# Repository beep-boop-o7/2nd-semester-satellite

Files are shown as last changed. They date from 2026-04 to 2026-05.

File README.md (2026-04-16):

# 2nd-semester-satellite

## Includes
Put your nonstandard library includes here (the ones you had to install separately)
available in the arduino ide unless otherwise noted

## How to use git (and github)
make sure git is installed.

### Setup

initilize a git instance in the directory(folder) that you want the project stored in
```
git init
```

clone the repo(repository) (copy it to your computer)
```
git clone https://github.com/beep-boop-o7/2nd-semester-satellite.git
```

set repo as origin
```
git remote add origin https://github.com/beep-boop-o7/2nd-semester-satellite.git
```

### Using

make a new branch for the feature you are working on (only do this for new features)
```
git checkout -b subsystem/feature_name
```

add changes to local branch (add all untracked)
```
git add -i
```

commit the changes you have made to the local branch (with a brief description)
```
git commit -m "This is a brief description"
```

push your local branch upstream (to github)
```
git push -u origin subsystem/feature_name
```
after that you go into github to make a merge request to merge your branch into main

to pull the latest changes from main
```
git pull
```

if git complains about unsaved changes
```
git stash
```

a helpful resource 
https://education.github.com/git-cheat-sheet-education.pdf

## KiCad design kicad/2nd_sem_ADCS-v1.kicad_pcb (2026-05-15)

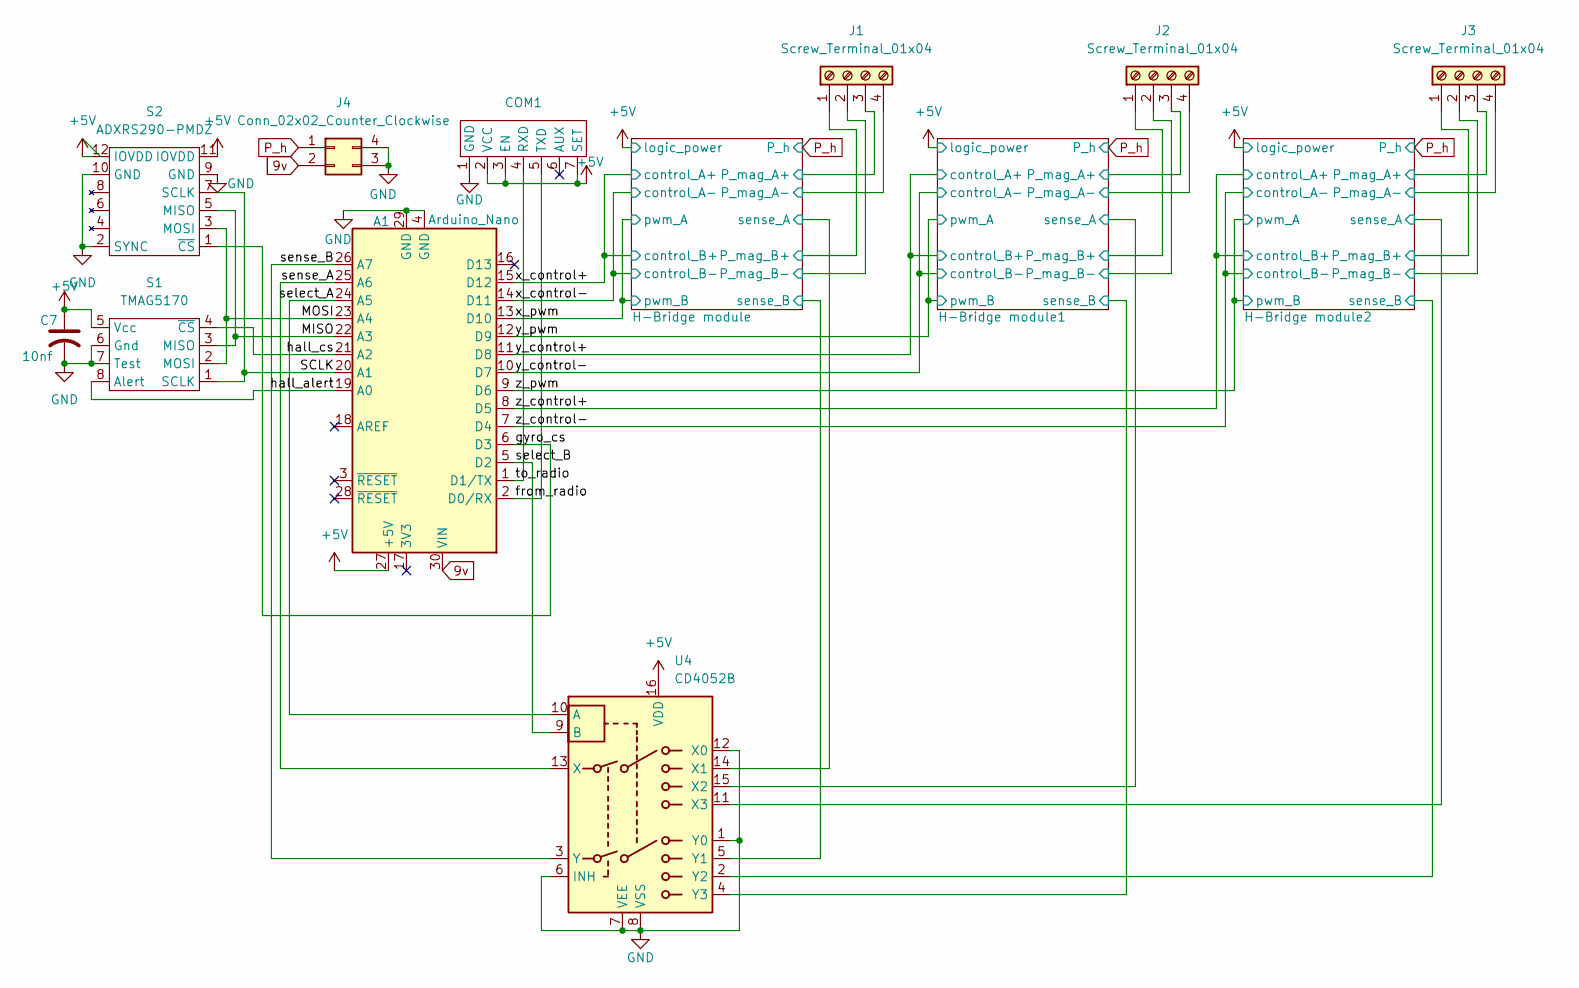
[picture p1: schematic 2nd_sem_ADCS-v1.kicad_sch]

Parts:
A1: Arduino_Nano
C7: 10nf; C_0805_2012Metric
COM1: PinHeader_1x07_P2.54mm_Vertical
J1, J2, J3: Screw_Terminal_01x04; TerminalBlock_Xinya_XY308-2.54-4P_1x04_P2.54mm_Horizontal
J4: Conn_02x02_Counter_Clockwise; PinHeader_2x02_P2.54mm_Vertical
S1: TMAG5170; VSSOP-8_3x3mm_P0.65mm
S2: ADXRS290-PMDZ; PinHeader_2x06_P2.54mm_Vertical
U4: CD4052B; DIP-16_W7.62mm

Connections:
9v: A1.30 (VIN), J4.2
+5V: A1.27 (+5V), C7.1, COM1.2 (VCC), COM1.3 (EN), COM1.7 (SET), S1.5 (Vcc), S2.11 (IOVDD), S2.12 (IOVDD), U4.16 (VDD); also elsewhere on the board
/H-Bridge module1/P_mag_A+: J2.3; also elsewhere on the board
/H-Bridge module1/P_mag_A-: J2.4; also elsewhere on the board
/H-Bridge module1/P_mag_B+: J2.1; also elsewhere on the board
/H-Bridge module1/P_mag_B-: J2.2; also elsewhere on the board
/H-Bridge module1/sense_A: U4.15 (X2); also elsewhere on the board
/H-Bridge module1/sense_B: U4.4 (Y3); also elsewhere on the board
/H-Bridge module2/P_mag_A+: J3.3; also elsewhere on the board
/H-Bridge module2/P_mag_A-: J3.4; also elsewhere on the board
/H-Bridge module2/P_mag_B+: J3.1; also elsewhere on the board
/H-Bridge module2/P_mag_B-: J3.2; also elsewhere on the board
/H-Bridge module2/sense_A: U4.11 (X3); also elsewhere on the board
/H-Bridge module2/sense_B: U4.2 (Y2); also elsewhere on the board
/H-Bridge module/P_mag_A+: J1.3; also elsewhere on the board
/H-Bridge module/P_mag_A-: J1.4; also elsewhere on the board
/H-Bridge module/P_mag_B+: J1.1; also elsewhere on the board
/H-Bridge module/P_mag_B-: J1.2; also elsewhere on the board
/H-Bridge module/sense_A: U4.14 (X1); also elsewhere on the board
/H-Bridge module/sense_B: U4.5 (Y1); also elsewhere on the board
/MISO: A1.22 (A3), S1.3 (MISO), S2.5 (MISO)
/MOSI: A1.23 (A4), S1.2 (MOSI), S2.3 (MOSI)
/SCLK: A1.20 (A1), S1.1 (SCLK), S2.7 (SCLK)
/from_radio: A1.2 (D0/RX), COM1.5 (TXD)
/gyro_cs: A1.6 (D3), S2.1 (~CS)
/hall_alert: A1.19 (A0), S1.8 (Alert)
/hall_cs: A1.21 (A2), S1.4 (~CS)
/select_A: A1.24 (A5), U4.10 (A)
/select_B: A1.5 (D2), U4.9 (B)
/sense_A: A1.25 (A6), U4.13 (X)
/sense_B: A1.26 (A7), U4.3 (Y)
/to_radio: A1.1 (D1/TX), COM1.4 (RXD)
/x_control+: A1.15 (D12); also elsewhere on the board
/x_control-: A1.14 (D11); also elsewhere on the board
/x_pwm: A1.13 (D10); also elsewhere on the board
/y_control+: A1.11 (D8); also elsewhere on the board
/y_control-: A1.10 (D7); also elsewhere on the board
/y_pwm: A1.12 (D9); also elsewhere on the board
/z_control+: A1.8 (D5); also elsewhere on the board
/z_control-: A1.7 (D4); also elsewhere on the board
/z_pwm: A1.9 (D6); also elsewhere on the board
GND: A1.4 (GND), A1.29 (GND), C7.2, COM1.1 (GND), J4.3, J4.4, S1.6 (Gnd), S1.7 (Test), S2.2 (SYNC), S2.9 (GND), S2.10 (GND), U4.1 (Y0), U4.6 (INH), U4.7 (VEE), U4.8 (VSS), U4.12 (X0); also elsewhere on the board
P_h: J4.1; also elsewhere on the board

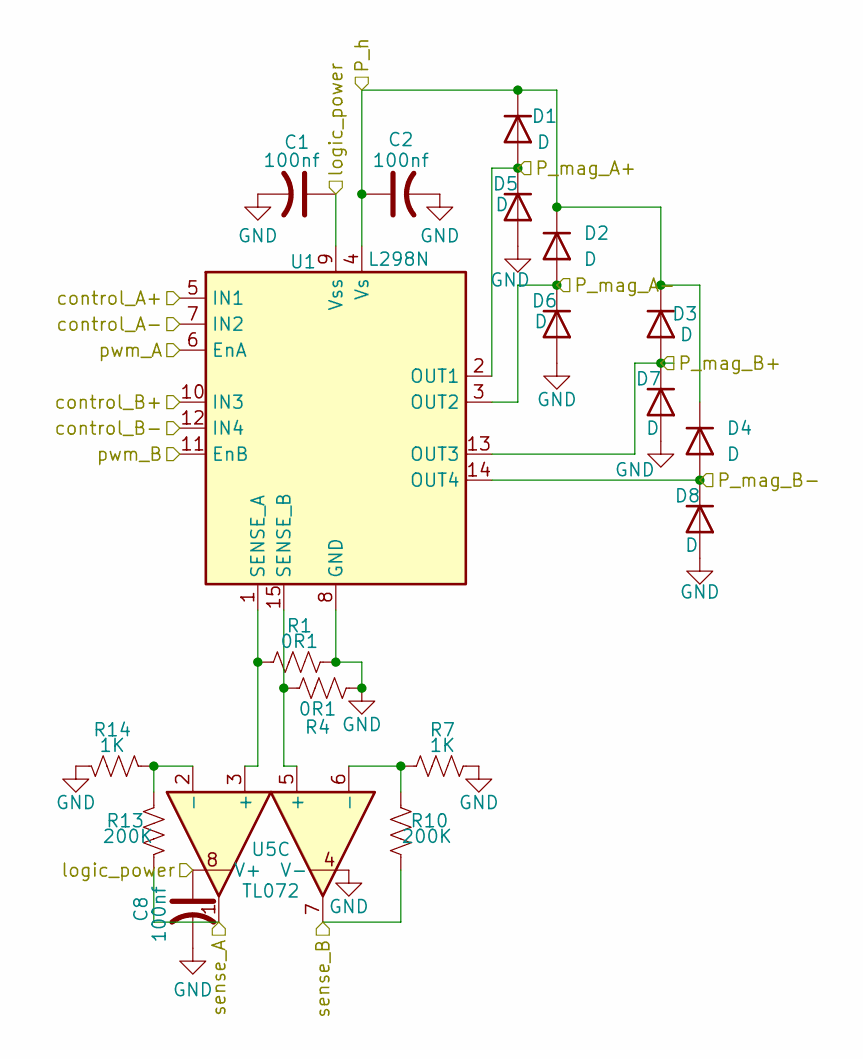
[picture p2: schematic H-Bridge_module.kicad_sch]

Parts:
C1, C2, C8: 100nf; C_0805_2012Metric
D1, D2, D3, D4, D5, D6, D7, D8: D; D_SOD-123
R1, R4: 0R1; R_0805_2012Metric
R7, R14: 1K; R_0805_2012Metric
R10, R13: 200K; R_0805_2012Metric
U1: L298N; TO-220-15_P2.54x5.08mm_StaggerOdd_Lead4.58mm_Vertical
U5: TL072; DIP-8_W7.62mm_Socket

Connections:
+5V: C1.1, C8.1, U1.9 (Vss), U5.8 (V+); also elsewhere on the board
/H-Bridge module/P_mag_A+: D1.2 (A), D5.1 (K), U1.2 (OUT1); also elsewhere on the board
/H-Bridge module/P_mag_A-: D2.2 (A), D6.1 (K), U1.3 (OUT2); also elsewhere on the board
/H-Bridge module/P_mag_B+: D3.2 (A), D7.1 (K), U1.13 (OUT3); also elsewhere on the board
/H-Bridge module/P_mag_B-: D4.2 (A), D8.1 (K), U1.14 (OUT4); also elsewhere on the board
/H-Bridge module/sense_A: R13.2, U5.1; also elsewhere on the board
/H-Bridge module/sense_B: R10.2, U5.7; also elsewhere on the board
/x_control+: U1.5 (IN1), U1.10 (IN3); also elsewhere on the board
/x_control-: U1.7 (IN2), U1.12 (IN4); also elsewhere on the board
/x_pwm: U1.6 (EnA), U1.11 (EnB); also elsewhere on the board
GND: C1.2, C2.2, C8.2, D5.2 (A), D6.2 (A), D7.2 (A), D8.2 (A), R1.2, R4.2, R7.2, R14.2, U1.8 (GND), U5.4 (V-); also elsewhere on the board
unnamed: R1.1, U1.1 (SENSE_A), U5.3 (+)
unnamed: R4.1, U1.15 (SENSE_B), U5.5 (+)
unnamed: R13.1, R14.1, U5.2 (-)
unnamed: R7.1, R10.1, U5.6 (-)
P_h: C2.1, D1.1 (K), D2.1 (K), D3.1 (K), D4.1 (K), U1.4 (Vs); also elsewhere on the board

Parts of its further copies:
C3, C4, C5, C6, C9, C10: 100nf; C_0805_2012Metric
D9, D10, D11, D12, D13, D14, D15, D16, D17, D18, D19, D20, D21, D22, D23, D24: D; D_SOD-123
R2, R3, R5, R6: 0R1; R_0805_2012Metric
R8, R9, R16, R18: 1K; R_0805_2012Metric
R11, R12, R15, R17: 200K; R_0805_2012Metric
U2, U3: L298N; TO-220-15_P2.54x5.08mm_StaggerOdd_Lead4.58mm_Vertical
U6, U7: TL072; DIP-8_W7.62mm_Socket

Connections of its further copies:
+5V: C3.1, C5.1, C9.1, C10.1, U2.9 (Vss), U3.9 (Vss), U6.8 (V+), U7.8 (V+); also elsewhere on the board
/H-Bridge module1/P_mag_A+: D9.2 (A), D10.1 (K), U2.2 (OUT1); also elsewhere on the board
/H-Bridge module1/P_mag_A-: D11.2 (A), D12.1 (K), U2.3 (OUT2); also elsewhere on the board
/H-Bridge module1/P_mag_B+: D13.2 (A), D14.1 (K), U2.13 (OUT3); also elsewhere on the board
/H-Bridge module1/P_mag_B-: D15.2 (A), D16.1 (K), U2.14 (OUT4); also elsewhere on the board
/H-Bridge module1/sense_A: R15.2, U6.1; also elsewhere on the board
/H-Bridge module1/sense_B: R11.2, U6.7; also elsewhere on the board
/H-Bridge module2/P_mag_A+: D17.2 (A), D18.1 (K), U3.2 (OUT1); also elsewhere on the board
/H-Bridge module2/P_mag_A-: D19.2 (A), D20.1 (K), U3.3 (OUT2); also elsewhere on the board
/H-Bridge module2/P_mag_B+: D21.2 (A), D22.1 (K), U3.13 (OUT3); also elsewhere on the board
/H-Bridge module2/P_mag_B-: D23.2 (A), D24.1 (K), U3.14 (OUT4); also elsewhere on the board
/H-Bridge module2/sense_A: R17.2, U7.1; also elsewhere on the board
/H-Bridge module2/sense_B: R12.2, U7.7; also elsewhere on the board
/y_control+: U2.5 (IN1), U2.10 (IN3); also elsewhere on the board
/y_control-: U2.7 (IN2), U2.12 (IN4); also elsewhere on the board
/y_pwm: U2.6 (EnA), U2.11 (EnB); also elsewhere on the board
/z_control+: U3.5 (IN1), U3.10 (IN3); also elsewhere on the board
/z_control-: U3.7 (IN2), U3.12 (IN4); also elsewhere on the board
/z_pwm: U3.6 (EnA), U3.11 (EnB); also elsewhere on the board
GND: C3.2, C4.2, C5.2, C6.2, C9.2, C10.2, D10.2 (A), D12.2 (A), D14.2 (A), D16.2 (A), D18.2 (A), D20.2 (A), D22.2 (A), D24.2 (A), R2.2, R3.2, R5.2, R6.2, R8.2, R9.2, R16.2, R18.2, U2.8 (GND), U3.8 (GND), U6.4 (V-), U7.4 (V-); also elsewhere on the board
unnamed: R2.1, U2.1 (SENSE_A), U6.3 (+)
unnamed: R5.1, U2.15 (SENSE_B), U6.5 (+)
unnamed: R3.1, U3.1 (SENSE_A), U7.3 (+)
unnamed: R6.1, U3.15 (SENSE_B), U7.5 (+)
unnamed: R15.1, R16.1, U6.2 (-)
unnamed: R8.1, R11.1, U6.6 (-)
unnamed: R17.1, R18.1, U7.2 (-)
unnamed: R9.1, R12.1, U7.6 (-)
P_h: C4.1, C6.1, D9.1 (K), D11.1 (K), D13.1 (K), D15.1 (K), D17.1 (K), D19.1 (K), D21.1 (K), D23.1 (K), U2.4 (Vs), U3.4 (Vs); also elsewhere on the board

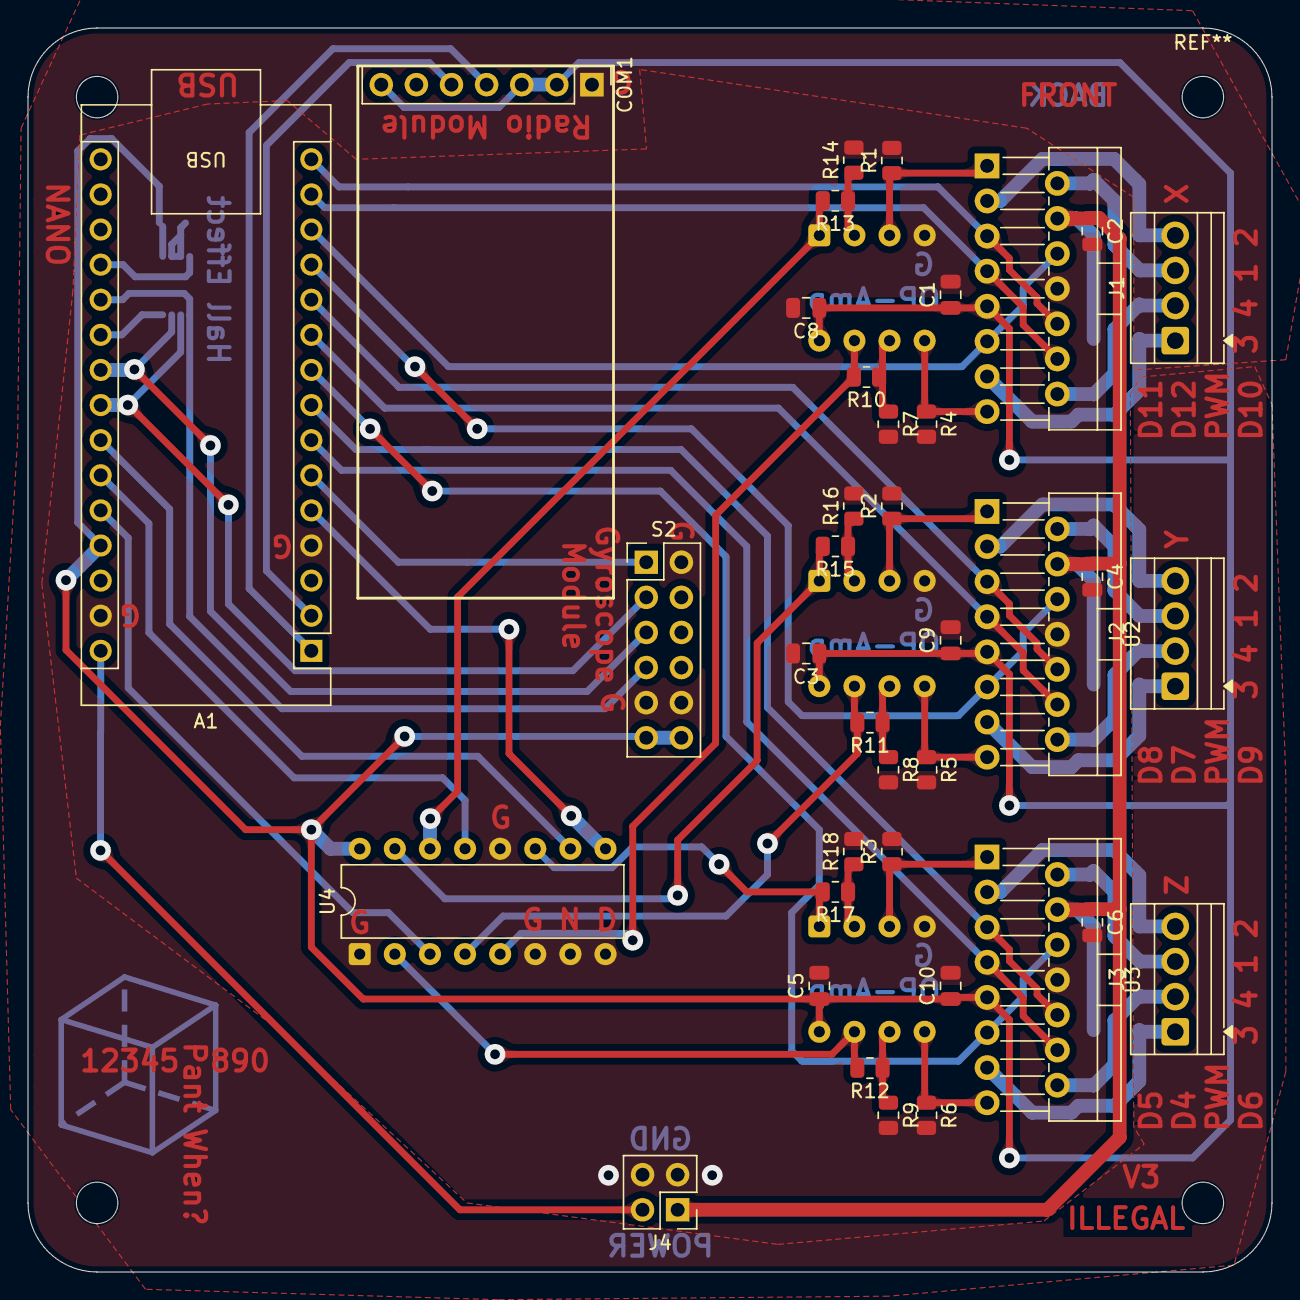
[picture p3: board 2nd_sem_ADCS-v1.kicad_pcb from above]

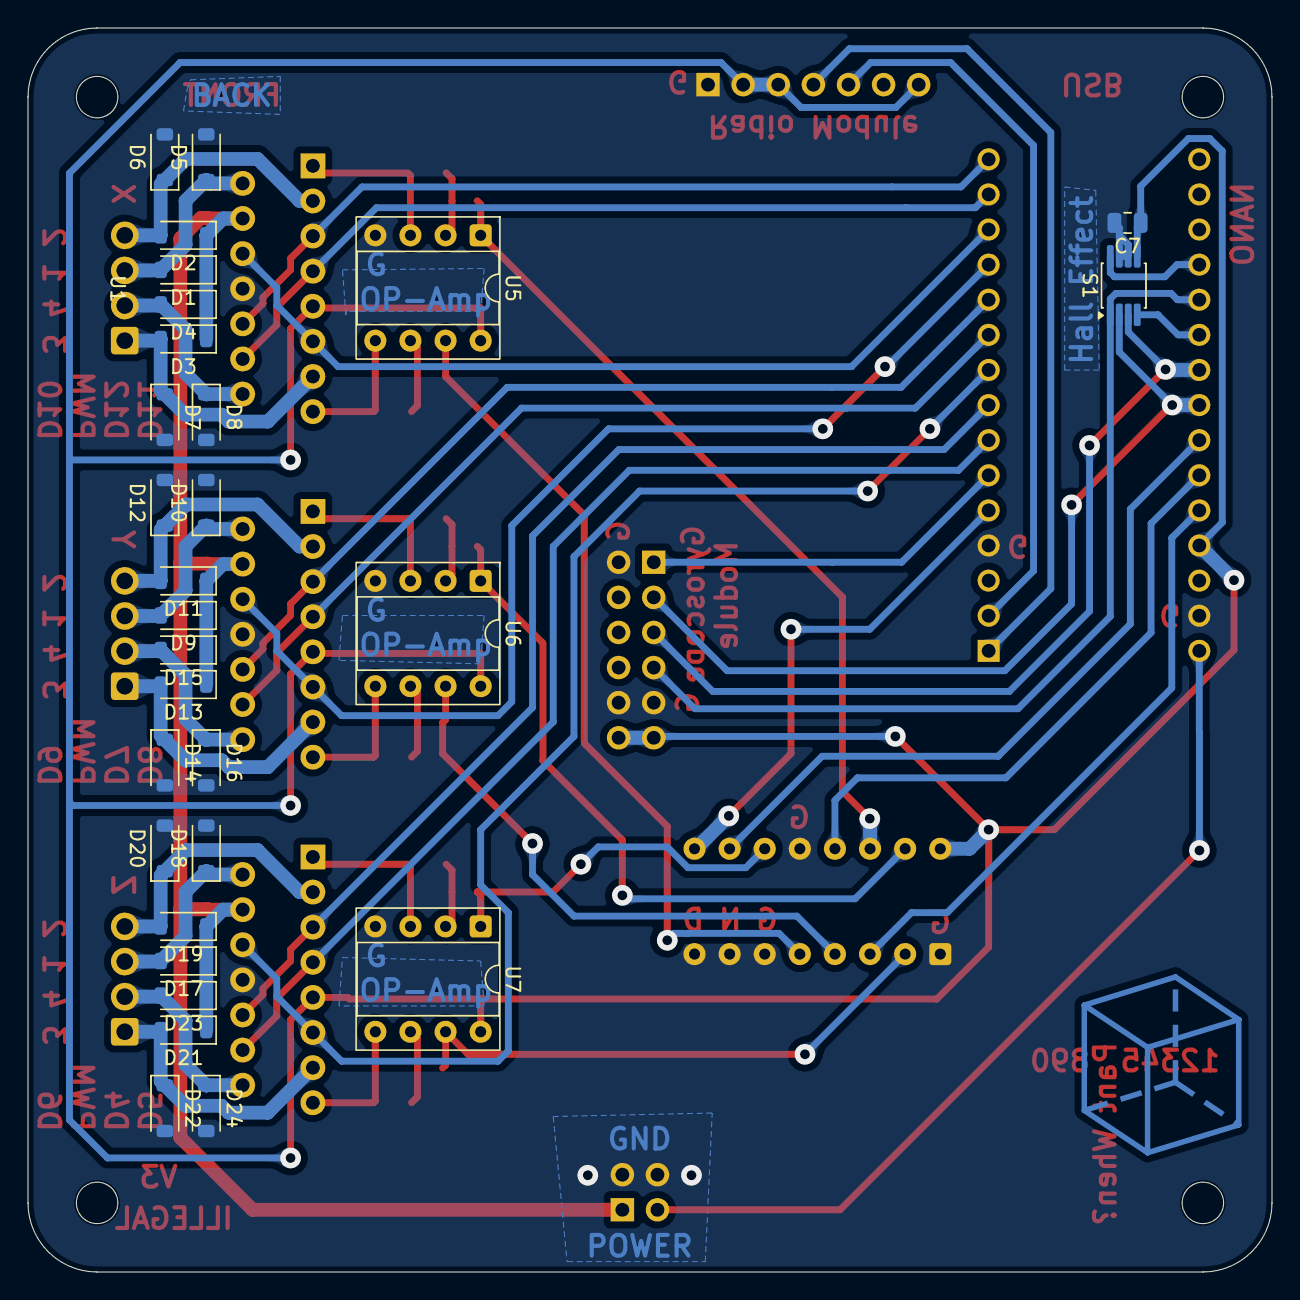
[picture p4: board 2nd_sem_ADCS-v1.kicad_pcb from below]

Board: 2 copper layers, 90.0 x 90.0 mm, 67 parts (29 on the bottom side), 55 nets.

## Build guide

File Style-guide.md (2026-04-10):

# Style guide

## whitespace

curly brackets start on the same line one space after the function they belong to is declared
ex.
```
loop() {
  thing
}
```

else statements start after the closing curly bracket of an if statement
ex.
```
if(something) {
  code
}else {
  other_code
}
```

lines within curly brackets are given a number of tabs equal to how many curly brackets they are inside of
ex.
```
loop() {
  one_tab() {
    2 tabs
  }
}
```

between two functions there is a newline
ex.
```
void func1() {
  thing
}

void func2() {
  thing
}
```

comments should be alinged and seperated from code
ex.
```
code      //comment
more_code //comment
incorrect//spacing

```

## best practises

use only ASCII characters

avoid having code that is nested more than 3 times, if possible make a sub function
ex.
```
void func1() {
  if(something) {
    while(something else) {
      func2();
    }
  }
}

void func2() {
  if(another thing) {
    code
  }
}
```

if code is reused make it a function
ex.
```
void func1() {
  func2();
  if(something) {
    func2();
  }
}

void func2() {
  code
}
```

always add comments for everything not explicit in the code
ex.
```
int func1() {
  z = x + y;
  func2(z);  //does thing
}

int func2(int z) {
  code
}
```

where possible use c functions instead of c++ functions

avoid using global variables where possible

do not use exeptions

always initailze variables

variables are lowercase with underscores between words
ex.
```
int this_is_an_example_variable = 0;
```

the start of word in a function is capitalized and words are seperated by underscores
ex.
```
void This_Is_An_Example_Function()
```

defines are fuly capitalized with underscores between words
ex.
```
#define THIS_IS_AN_EXAMPLE_DEFINE
```

add ifndef to header files to prevent duplicate inclusion
ex.
```
#ifndef Header_filename
#define Header_filename

  //Header declarations…

#endif
```

more reading https://www.stroustrup.com/JSF-AV-rules.pdf

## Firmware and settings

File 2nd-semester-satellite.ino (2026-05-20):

#include "src/Sensor/hall_effect_sensor.h"
#include "src/Sensor/Gyro.h"
#include "src/Sensor/rt_spi.h"
#include "src/Kontrollogik/Kontrollogik.h"
#include "src/Aktuator/Aktuator.h"
#include <Arduino.h>
#include <math.h>
#include <krnl.h>

#define SPI_CLOCK A1
#define SPI_MOSI A4
#define SPI_MISO A3
#define HALL_CS_PIN A2
#define HALL_ALERT_PIN A0
#define GYRO_CS_PIN 3
#define X_AXIS_A 12
#define X_AXIS_B 11
#define X_AXIS_PWM 10
#define Y_AXIS_A 8
#define Y_AXIS_B 7
#define Y_AXIS_PWM 9
#define Z_AXIS_A 5
#define Z_AXIS_B 4
#define Z_AXIS_PWM 6
#define MULTIPLEX_A A5
#define MULTIPLEX_B 2
#define SENS_A A6
#define SENS_B A7
#define MAXIMUM_MILLIAMPRE 200  //for now

#define STK 300
char t1[STK], t2[STK], t3[STK], t4[STK], t5[STK];

struct k_t *pTask_Hall, *pTask_Gyro, *pTask_Control, *pTask_Mag, *pTask_C2;

struct k_t *Timed_Sem1, *Timed_Sem2, *Timed_Sem3, *Magnetic_Sem;

hall_sensor_data Hall_Data_Queue[2];

gyro_sensor_data Gyro_Data_Queue[2];

control_data Mag_Data_Queue[2];

control_data C2_Data_Queue[2];

struct k_msg_t *Queue_Hall, *Queue_Gyro, *Queue_Mag, *Queue_C2;

void Task_Hall() {
  //setup hall effect sensor
  hall_sensor_data hall_data;

  k_set_sem_timer(Timed_Sem1, 100);

  pinMode(HALL_CS_PIN, OUTPUT);
  pinMode(HALL_ALERT_PIN, OUTPUT);
  digitalWrite(HALL_CS_PIN, HIGH);
  digitalWrite(HALL_ALERT_PIN, HIGH);

  Init_TMAG(HALL_CS_PIN);

  while (1) {
    //loop hall effect sensor
    k_wait(Timed_Sem1, 0);  //read every 100ms
    k_wait(Magnetic_Sem, 0);  //mutex with magnetorquer
    
    Read_TMAG(&hall_data, HALL_CS_PIN, HALL_ALERT_PIN);

    k_signal(Magnetic_Sem);
    
    k_send(Queue_Hall, &hall_data);
  }
}

void Task_Gyro() {
  //setup gyroscope
  gyro_sensor_data gyro_data;

  k_set_sem_timer(Timed_Sem2, 20);

  pinMode(GYRO_CS_PIN, OUTPUT);
  digitalWrite(GYRO_CS_PIN, HIGH);

  Gyro_Setup(GYRO_CS_PIN);

  while (1) {
    //loop gyroscope
    k_wait(Timed_Sem2, 0);

    Update_Gyro(&gyro_data, GYRO_CS_PIN);

    k_send(Queue_Gyro, &gyro_data);
  }
}

void Task_Control() {
  //setup control
  hall_sensor_data hall_tmp;  //temp buckets for message queue
  gyro_sensor_data gyro_tmp;
  control_data gyro_data, hall_data, command_direction, output_data, C2_tmp;
  int missed;

  hall_data.x = 1;
  hall_data.y = 0;
  hall_data.z = 0;

  gyro_data.x = 1;
  gyro_data.y = 0;
  gyro_data.z = 0;

  command_direction.x = 1;
  command_direction.y = 0;
  command_direction.z = 0;

  double z_angle = 0;

  k_set_sem_timer(Timed_Sem3, 1000);

  while (1) {
    //loop control
    if (k_receive(Queue_C2, &C2_tmp, -1, &missed) != -1) {
      command_direction = C2_tmp;
    }

    if (k_receive(Queue_Hall, &hall_tmp, -1, &missed) != -1) {
      hall_data.x = hall_tmp.x;
      hall_data.y = hall_tmp.y;
      hall_data.z = hall_tmp.z;
    }

    if (k_receive(Queue_Gyro, &gyro_tmp, -1, &missed) != -1) {
      //if 3 axis gyro copy twice
      gyro_data.z = gyro_tmp.rate;
      float z_rotation = atan2f(command_direction.y, command_direction.x);  //update direction
      float z_new_rotation = z_rotation + (gyro_tmp.Angle - z_angle);
      float z_scale = (sqrt(sq(command_direction.x) + sq(command_direction.y)) / sqrt(sq(sin(z_new_rotation)) + sq(cos(z_new_rotation))));
      command_direction.x = sin(z_new_rotation) * z_scale;
      command_direction.y = cos(z_new_rotation) * z_scale;
    }

    if (k_wait(Timed_Sem3, -1) > 0) {
      Control_Magnetic(command_direction, gyro_data, hall_data, &output_data);
      Serial.print("values:");
      Serial.println(output_data.x );
      k_send(Queue_Mag, &output_data);
      k_sleep(1);
      Serial.print(F("rate:"));
      Serial.println(gyro_data.z);
      Serial.print(F("angle:"));
      Serial.println(gyro_tmp.Angle);
    }

    k_sleep(1);
  }
}

void Task_Mag() {
  //setup magnetorquer
  control_data tmp_cmd;
  int missed;
  Init_Magnetorquers(X_AXIS_A, X_AXIS_B, X_AXIS_PWM, Y_AXIS_A, Y_AXIS_B, Y_AXIS_PWM, Z_AXIS_A, Z_AXIS_B, Z_AXIS_PWM, MULTIPLEX_A, MULTIPLEX_B, SENS_A, SENS_B, MAXIMUM_MILLIAMPRE);
  while (1) {
    Serial.println("in mag");
    //loop magnetorquer
    k_receive(Queue_Mag, &tmp_cmd, 0, &missed);  //if command receved
   
    k_wait(Magnetic_Sem, 0);  //mutex with hall effect sensor
    
    aktuator_data data;
    data.x = tmp_cmd.x;
    data.y = tmp_cmd.y;
    data.z = 0.0;
    long int run_time = millis();
    Command_Magnetorquers(data);

    k_sleep(run_time - millis() + 800);  //80% run time

   Stop_Magnetorquers();
    k_signal(Magnetic_Sem);

    Serial.println(F("magIn"));
  }
}

control_data Convert_Msg(char *in_buffer) {
  control_data command;
  command.x = 0.0;
  command.y = 0.0;
  command.z = 0.0;
  char *buffer;  //<data|data|data>
  buffer = strsep(&in_buffer, "<");
  buffer = strsep(&in_buffer, "|");
  if (buffer == nullptr) return command;
  command.x = atof(buffer);
  buffer = strsep(&in_buffer, "|");
  if (buffer == nullptr) return command;
  command.y = atof(buffer);
  buffer = strsep(&in_buffer, "|");
  if (buffer == nullptr) return command;
  command.z = atof(buffer);
  return command;
}

void Task_C2() {
  control_data command;
  char in_buffer[40];
  uint8_t read_pos = 0;

  Serial.println(F("ready"));

  while (1) {
    if (Serial.available()) {
      char in_byte = Serial.read();
      if (in_byte == '<') {
        read_pos = 0;
      }

      if (in_byte == '>') {
        in_buffer[read_pos] = '\0';
        command = Convert_Msg(in_buffer);

        k_send(Queue_C2, &command);
      }

      in_buffer[read_pos] = in_byte;
      read_pos++;
    }
  }
}

void setup() {
  Serial.begin(115200);
  while (!Serial)
    ;

  Serial.println(F("Serial"));

  k_init(5, 5, 4);
  //     |  |  |-- num of msg Queues (4) hall effect, gyroscope, magnatorquer, C2
  //     |  |----- num of semaphores (5) SPI, timer 1-2-3, magnetic lockout
  //     |------------- num of tasks (5) hall, gyro, control, mag, C2

  Queue_Hall = k_crt_send_Q(2, sizeof(hall_sensor_data), Hall_Data_Queue);  // 4 elements of size
  Queue_Gyro = k_crt_send_Q(2, sizeof(gyro_sensor_data), Gyro_Data_Queue);  // 4 elements of size
  Queue_Mag = k_crt_send_Q(2, sizeof(control_data), Mag_Data_Queue);        // 4 elements of size
  Queue_C2 = k_crt_send_Q(2, sizeof(control_data), C2_Data_Queue);          // 4 elements of size

  pTask_Hall = k_crt_task(Task_Hall, 10, t1, STK);
  pTask_Gyro = k_crt_task(Task_Gyro, 10, t2, STK);
  pTask_Control = k_crt_task(Task_Control, 20, t3, STK);
  pTask_Mag = k_crt_task(Task_Mag, 15, t4, STK);
  pTask_C2 = k_crt_task(Task_C2, 30, t5, STK);

  Timed_Sem1 = k_crt_sem(0, 1);    // 0: start value, 1: max value (clipping)
  Timed_Sem2 = k_crt_sem(0, 1);    // 0: start value, 1: max value (clipping)
  Timed_Sem3 = k_crt_sem(0, 1);    // 0: start value, 1: max value (clipping)
  Magnetic_Sem = k_crt_sem(1, 1);  // 0: start value, 1: max value (clipping)

  Init_SPI(SPI_MOSI, SPI_MISO, SPI_CLOCK);

  Serial.println(F("k_start"));

  k_start(); /* start krnl timer speed 1 milliseconds*/

  Serial.println(F("If you see this then krnl crashed :-("));
}

void loop() {}

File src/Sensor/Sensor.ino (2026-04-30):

#include "Gyro.h"
#include "hall_effect_sensor.h"
#include "rt_spi.h"
#include <krnl.h>
#include <Arduino.h>

#define SPI_CLOCK A0
#define SPI_MOSI A1
#define SPI_MISO A2
#define HALL_CS_PIN A3
#define HALL_ALERT_PIN A4
#define GYRO_CS_PIN A5

#define STK 150
char t1[STK], t2[STK], t3[STK];

struct k_t *pTask_Hall, *pTask_Gyro, *pTask_Print;

struct k_t *Timed_Sem1, *Timed_Sem2, *Timed_Sem3;

hall_sensor_data Hall_Data_Queue[4];

gyro_sensor_data Gyro_Data_Queue[4];

struct k_msg_t *Queue_Hall, *Queue_Gyro;

void Task_Hall() {
    hall_sensor_data hall_data;

    k_set_sem_timer(Timed_Sem1, 100);

    pinMode(HALL_CS_PIN, OUTPUT);
    pinMode(HALL_ALERT_PIN, OUTPUT);
	digitalWrite(HALL_CS_PIN, HIGH);
    digitalWrite(HALL_ALERT_PIN, HIGH);

    Init_TMAG(HALL_CS_PIN);

    while (1) {
        k_wait(Timed_Sem1, 0);

        Read_TMAG(&hall_data, HALL_CS_PIN, HALL_ALERT_PIN);

        k_send(Queue_Hall, &hall_data);
    }
}

void Task_Gyro() {
    gyro_sensor_data gyro_data;

    k_set_sem_timer(Timed_Sem2, 50);

    pinMode(GYRO_CS_PIN, OUTPUT);
    digitalWrite(GYRO_CS_PIN, HIGH);

    Gyro_Setup(GYRO_CS_PIN);

    while (1) {
        k_wait(Timed_Sem2, 0);

        Update_Gyro(&gyro_data, GYRO_CS_PIN);

        k_send(Queue_Gyro, &gyro_data);
    }
}

void Task_Print() {
    hall_sensor_data hall_data, hall_tmp;
    gyro_sensor_data gyro_data, gyro_tmp;
    int missed;

    hall_data.x = 0;
    hall_data.y = 0;
    hall_data.z = 0;

    gyro_data.Angle = 0;
    gyro_data.rate = 0;

    k_set_sem_timer(Timed_Sem3, 1000);

    while (1) {
        if(k_receive(Queue_Hall, &hall_tmp, -1, &missed) != -1) {
            hall_data = hall_tmp;
        }
        if(k_receive(Queue_Gyro, &gyro_tmp, -1, &missed) != -1) {
            gyro_data = gyro_tmp;
        }
        if(k_wait(Timed_Sem3, -1) > 0) {
            Serial.println("Hall Data");
            Serial.print("x: ");
            Serial.print(hall_data.x);
            Serial.print(" y: ");
            Serial.print(hall_data.y);
            Serial.print(" z: ");
            Serial.println(hall_data.z);
            Serial.println("Gyro Data");
            Serial.print("angle: ");
            Serial.print(gyro_data.Angle);
            Serial.print(" rate: ");
            Serial.println(gyro_data.rate);
        }
    }
}

void setup() {
	Serial.begin(115200);
    while (!Serial);    
	
	Serial.println("just bef init part");
	
	k_init(3, 4, 2);
	//     |  |  |-- num of msg Queues (2) hall effect, gyroscope
	//     |  |----- num of semaphores (4) SPI, timer 1-2-3
	//     |------------- num of tasks (3) hall, gyro, print
	
	Queue_Hall = k_crt_send_Q(4, sizeof(hall_sensor_data),  Hall_Data_Queue);  // 4 elements of size
	Queue_Gyro = k_crt_send_Q(4, sizeof(gyro_sensor_data),  Gyro_Data_Queue);  // 4 elements of size

	pTask_Hall = k_crt_task(Task_Hall, 10, t1, STK);
	pTask_Gyro = k_crt_task(Task_Gyro, 10 , t2, STK);
    pTask_Print = k_crt_task(Task_Print, 20, t3, STK);

	Timed_Sem1 = k_crt_sem(0, 1); // 0: start value, 1: max value (clipping)
	Timed_Sem2 = k_crt_sem(0, 1); // 0: start value, 1: max value (clipping)
    Timed_Sem3 = k_crt_sem(0, 1); // 0: start value, 1: max value (clipping)

    Init_SPI(SPI_MOSI, SPI_MISO, SPI_CLOCK);

	Serial.println("just bef k_start");
	
	k_start(); /* start krnl timer speed 1 milliseconds*/
	
	Serial.println("If you see this then krnl crashed :-(");
}

void loop() {}

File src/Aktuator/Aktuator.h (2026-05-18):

#ifndef Aktuator
#define Aktuator

#include <Arduino.h>
#include <math.h>

typedef struct{
    float x, y, z;
} aktuator_data;

/**
 * @brief fast stops magnetorquers by grounding both side of the H-bridge
 */
void Stop_Magnetorquers();

/**
 * @brief sets current flowing through each axis to (max_mA * control_vector.(x,y,z) * 2)
 * @param control_vector 3d vector with values between 1 and -1 representing % strength
 */
void Command_Magnetorquers(aktuator_data control_vector);

/**
 * @brief sets all pins for use in other functions and sets max mA per coil
 * @param x_A A pin connected to x
 * @param y_A A pin connected to y
 * @param z_A A pin connected to z
 * @param select_A A pin connected to select
 * @param sens_A A pin connected to sens
 * @param x_B B pin connected to x
 * @param y_B B pin connected to y
 * @param z_B B pin connected to z
 * @param select_B B pin connected to select
 * @param sens_B B pin connected to sens
 * @param x_PWM PWM pin connected to x
 * @param y_PWM PWM pin connected to y
 * @param z_PWM PWM pin connected to z
 * @param max_mA max milliAmpere you want to pull on each coil (2 coils per axis)
 */
void Init_Magnetorquers(uint8_t x_A, uint8_t x_B, uint8_t x_PWM, uint8_t y_A, uint8_t y_B, uint8_t y_PWM, uint8_t z_A, uint8_t z_B, uint8_t z_PWM, uint8_t select_A, uint8_t select_B, uint8_t sens_A, uint8_t sens_B, float max_mA);

#endif

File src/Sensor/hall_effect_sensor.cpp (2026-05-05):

#include "hall_effect_sensor.h"

void Clear_TMAG_SPI_Errors(int CS_pin, SPI_data_32 *spi_data) {
    SPI_Read_32_CRC(CS_pin, 0, 0x0D, 0, spi_data);
	delay(10);
	SPI_Read_32_CRC(CS_pin, 0, 0x0D, 0, spi_data);
	delay(10);
}

void Read_TMAG(hall_sensor_data *data, int CS_pin, int alert_pin) {
    SPI_data_32 spi_data;
    digitalWrite(alert_pin, LOW);
    k_sleep(10);
    digitalWrite(alert_pin, HIGH);
    k_sleep(100);
	SPI_Read_32_CRC(CS_pin, 0, 0x9, 0, &spi_data);
	data->x = ((double) ((int16_t)spi_data.data)) / 1308.0;

	SPI_Read_32_CRC(CS_pin, 0, 0xA, 0, &spi_data);
	data->y = ((double) ((int16_t)spi_data.data)) / 1308.0;

	SPI_Read_32_CRC(CS_pin, 0, 0xB, 0, &spi_data);
	data->z = ((double) ((int16_t)spi_data.data)) / 1308.0;
}

void Init_TMAG(int CS_pin) {
    SPI_data_32 spi_data;

    Clear_TMAG_SPI_Errors(CS_pin, &spi_data);

	//set DEVICE_CONFIG Register
    spi_data.data = 0b0010100000110000; //32x conversion avg (0101) and active trigger mode (011)
	SPI_Write_32_CRC(CS_pin, 0, 0x0, 0, &spi_data);
	//set SENSOR_CONFIG Register
	spi_data.data = 0b0000000111010101; //enable x, y, z chanels (0111) and set resolution to +-25mt (01)
	SPI_Write_32_CRC(CS_pin, 0, 0x1, 0, &spi_data);
    //set SYSTEM_CONFIG Register
    spi_data.data = 0b0000010000000000; //set trigger to alert low (10)
	SPI_Write_32_CRC(CS_pin, 0, 0x2, 0, &spi_data);
}

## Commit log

2026-04-20 Prototype 1
2026-04-20 Prototype 1 fixed
2026-04-20 Fixed Prototype 1 fixed
2026-04-21 add SPI interface
2026-04-28 Add gyroSetup function declaration
2026-04-28 Add CS_PIN definition to Gyro.h
2026-04-29 Add documentation for gyroSetup function
    Lavede kommentar
2026-04-29 move hall code to proper directory
2026-04-30 Create Gyro_kode_og_wireless_transmission.ino
    gyro test kode med esp32
2026-05-04 Add additional SPI write for Gyro filter mode
2026-05-15 add kicad files for v3 of circit
    [2nd_sem_ADCS-v1.kicad_pcb, 2nd_sem_ADCS-v1.kicad_sch, H-Bridge_module.kicad_sch]
2026-05-17 actuator code
2026-05-17 actuator code (for real this time)
2026-05-17 actuator code (for real this time (with .h))
2026-05-18 make PID mork more corectly
2026-05-19 print gyro data
